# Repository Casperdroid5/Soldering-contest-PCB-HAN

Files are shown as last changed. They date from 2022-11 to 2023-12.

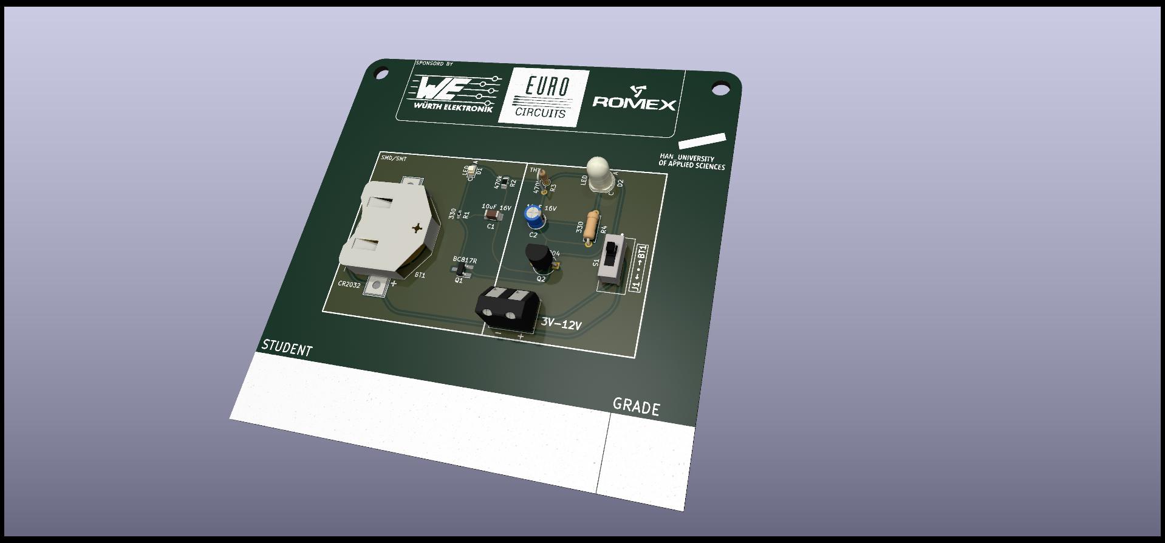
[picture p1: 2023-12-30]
Pictures PCB/Soldering contest PCB HAN.jpg

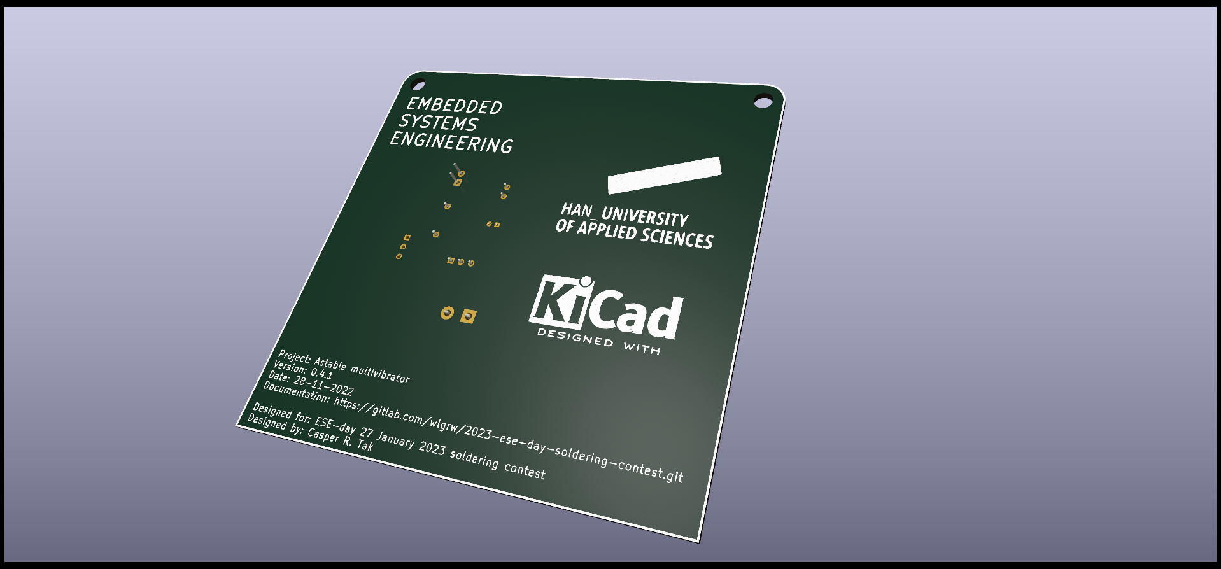
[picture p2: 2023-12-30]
Pictures PCB/Soldering contest PCB HAN-Back.png

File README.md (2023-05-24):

# Soldering Contest PCB (HAN)

The PCB has been created specifically for the soldering contest. It is designed to help students in the ESE course develop their soldering skills for both surface-mount (SMD) and through-hole (THT) components of different sizes.

## Key Features

- **Component Variety:** The PCB includes a diverse range of SMD and THT components of different sizes and types. This allows students to practice soldering techniques for various components.

- **Component Footprints:** Different component footprints are included on the PCB to accommodate various package types such as resistors, capacitors, diodes, ICs, and connectors. This exposes students to different soldering techniques required for each component type.

- **Test Points:** The PCB features strategically placed test points that enable instructors to measure the quality of solder joints. These test points assess students' soldering technique and the electrical connectivity of the components.

- **Thermal Pads:** Components with thermal pads are incorporated to test students' ability to handle heat dissipation during soldering. This provides experience in soldering components that require special attention to avoid overheating or cold solder joints.

- **Solder Mask Openings:** Small solder mask openings are introduced on some pads to assess students' precision and control during soldering. This challenges them to avoid bridging adjacent pads or leaving solder residues on the mask.

- **Multiple Soldering Techniques:** The PCB is designed to encourage the use of different soldering techniques. It includes components that require drag soldering, reflow soldering, or hand-soldering under a microscope. This helps students become proficient in a variety of soldering methods.

- **Soldering Station Settings:** Clear guidelines or recommendations for soldering station settings are provided, including temperature, soldering iron tip selection, and solder types suitable for the components on the PCB. This helps students understand the importance of proper soldering equipment setup for different scenarios.

- **Grading Criteria:** A grading rubric is defined, covering soldering technique, joint appearance, component alignment, cleanliness, and electrical continuity. This ensures students understand how their work will be evaluated.

- **Documentation and Resources:** Documentation or resources such as a soldering guide or reference materials are provided for students to refer to during the contest. This helps familiarize them with best practices and techniques before starting their soldering tasks.

- **Safety Considerations:** Emphasis is placed on safety precautions during soldering, including proper ventilation, eye protection, and safe handling of soldering equipment. The contest follows appropriate safety protocols to protect the students and instructors.

## Soldering Tips and Advice

Soldering is a delicate process that requires skill, precision, and attention to detail. Here are some helpful tips and advice to assist students participating in the soldering contest:

1. **Prepare your workspace:** Ensure you have a clean and well-organized workspace. Remove any unnecessary clutter, and have all your tools and components easily accessible. A clutter-free area allows you to focus on the soldering task at hand and reduces the chances of accidental damage or mistakes.

2. **Inspect the PCB and components:** Before starting, carefully inspect the PCB and components for any defects or damage. Check for bent pins, damaged traces, or missing components. Address any issues before proceeding with soldering to avoid complications later.

3. **Choose the right soldering iron tip:** Select an appropriate soldering iron tip based on the component size and type. A fine-point tip works well for small SMD components, while a chisel or screwdriver tip is suitable for larger THT components. Ensure the tip is clean and properly tinned for optimal heat transfer.

4. **Maintain proper temperature:** Set the soldering iron temperature according to the solder and component requirements. Too high a temperature can damage components or lead to overheating, while too low a temperature can result in cold solder joints. Follow the recommended temperature range provided for the contest.

5. **Cleanliness is crucial:** Keep your soldering iron tip clean by regularly wiping it on a damp sponge or brass tip cleaner. This helps remove oxidation and ensures good heat transfer. Additionally, keep the components, PCB, and soldering area clean from flux residues or excess solder. Use flux remover or isopropyl alcohol for cleaning, if necessary.

6. **Practice good soldering technique:** Master the art of soldering by practicing proper technique. Hold the soldering iron like a pen, with a light grip, and apply gentle pressure. Ensure the tip touches both the pad and the component lead simultaneously to allow efficient heat transfer. Feed a small amount of solder at the junction, and let it flow smoothly.

7. **Avoid excessive heat:** Minimize the time the soldering iron spends in contact with the component leads or pads to prevent overheating. Prolonged exposure to heat can damage sensitive components or surrounding parts. Develop a steady and controlled soldering rhythm to ensure quick, yet accurate, soldering.

8. **Prevent solder bridges:** Take care to avoid solder bridges, which occur when solder connects adjacent pads or pins. Use a magnifying glass or a microscope to closely inspect your work, especially when soldering small, closely spaced components. If solder bridges occur, use desoldering braid or a solder sucker to remove excess solder.

9. **Ensure proper joint formation:** Aim for shiny, concave solder joints that indicate a proper bond. Dull or irregular joints may indicate cold solder joints or insufficient solder. If needed, reheat the joint and add a small amount of solder to achieve a well-formed, reliable connection.

10. **Test continuity and functionality:** Once soldering is complete, use a multimeter or other appropriate testing methods to check the electrical continuity and functionality of the soldered components. This ensures that the connections are secure and the circuit operates as intended.

Remember, soldering is a skill that improves with practice. Take your time, be patient, and learn from each soldering experience. Don't hesitate to ask for guidance or clarification if you have any doubts. Enjoy the soldering process and have confidence in your abilities!

*Note: The soldering tips and advice provided here are general guidelines. Always refer to the specific instructions, safety precautions, and grading criteria provided by the contest organizers for accurate information and requirements.*

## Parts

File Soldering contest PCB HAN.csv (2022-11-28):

Source: | C:\Users\crtak\Documents\Projecten\Soldering contest PCB HAN\Solder-contest-PCB-HAN\Soldering contest PCB HAN.kicad_sch
Date: | 28/11/2022 10:49:19
Tool: | Eeschema (6.0.6)
Generator: | C:\Program Files\KiCad\6.0\bin\scripting\plugins/bom_csv_grouped_by_value.py
Component Count: | 15
Individual Components:
Item | Qty | Reference(s) | Value | LibPart | Footprint | Datasheet | Field4
 |  | BT1 | Battery_Cell | Device:Battery_Cell | Battery:BatteryHolder_Keystone_3002_1x2032 | ~
 |  | C1 | 10uF 16V | Device:C_Polarized | Capacitor_SMD:C_1206_3216Metric_Pad1.33x1.80mm_HandSolder | ~
 |  | C2 | 10uF 16V | Device:C_Polarized | Capacitor_THT:CP_Radial_D4.0mm_P2.00mm | ~
 |  | D1 | LED | Device:LED | LED_SMD:LED_0805_2012Metric_Pad1.15x1.40mm_HandSolder | ~
 |  | D2 | LED | Device:LED | LED_THT:LED_D5.0mm_Clear | ~
 |  | H1 | MountingHole | Mechanical:MountingHole | MountingHole:MountingHole_4.3mm_M4 | ~
 |  | H2 | MountingHole | Mechanical:MountingHole | MountingHole:MountingHole_4.3mm_M4 | ~
 |  | J1 | Screw_Terminal_01x02 | Connector:Screw_Terminal_01x02 | TerminalBlock:TerminalBlock_bornier-2_P5.08mm | ~
 |  | Q1 | BC817 | Transistor_BJT:2N3904 | Package_TO_SOT_SMD:SOT-23_Handsoldering | https://assets.nexperia.com/documents/data-sheet/BC817_SER.pdf
 |  | Q2 | 2N3904 | Transistor_BJT:2N3904 | Package_TO_SOT_THT:TO-92_Inline_Wide | https://www.onsemi.com/pub/Collateral/2N3903-D.PDF
 |  | R1 | 330 | Device:R | Resistor_SMD:R_0402_1005Metric | ~
 |  | R2 | 470k | Device:R | Resistor_SMD:R_0805_2012Metric_Pad1.20x1.40mm_HandSolder | ~
 |  | R3 | 470k | Device:R | Resistor_THT:R_Axial_DIN0204_L3.6mm_D1.6mm_P2.54mm_Vertical | ~
 |  | R4 | 330 | Device:R | Resistor_THT:R_Axial_DIN0207_L6.3mm_D2.5mm_P7.62mm_Horizontal | ~
 |  | S1 | SWITCH-SPDT-PTH-11.6X4.0MM-KIT | SparkFun-Switches:SWITCH-SPDT-PTH-11.6X4.0MM-KIT | SnapEDA Library:SW_1825159-1 |  | SWCH-08261
Collated Components:
Item | Qty | Reference(s) | Value | LibPart | Footprint | Datasheet | Field4
1 | 1 | BT1 | Battery_Cell | Device:Battery_Cell | Battery:BatteryHolder_Keystone_3002_1x2032 | ~
2 | 1 | C1 | 10uF 16V | Device:C_Polarized | Capacitor_SMD:C_1206_3216Metric_Pad1.33x1.80mm_HandSolder | ~
3 | 1 | C2 | 10uF 16V | Device:C_Polarized | Capacitor_THT:CP_Radial_D4.0mm_P2.00mm | ~
4 | 1 | D1 | LED | Device:LED | LED_SMD:LED_0805_2012Metric_Pad1.15x1.40mm_HandSolder | ~
5 | 1 | D2 | LED | Device:LED | LED_THT:LED_D5.0mm_Clear | ~
6 | 2 | H1, H2 | MountingHole | Mechanical:MountingHole | MountingHole:MountingHole_4.3mm_M4 | ~
7 | 1 | J1 | Screw_Terminal_01x02 | Connector:Screw_Terminal_01x02 | TerminalBlock:TerminalBlock_bornier-2_P5.08mm | ~
8 | 1 | Q1 | BC817 | Transistor_BJT:2N3904 | Package_TO_SOT_SMD:SOT-23_Handsoldering | https://assets.nexperia.com/documents/data-sheet/BC817_SER.pdf
9 | 1 | Q2 | 2N3904 | Transistor_BJT:2N3904 | Package_TO_SOT_THT:TO-92_Inline_Wide | https://www.onsemi.com/pub/Collateral/2N3903-D.PDF
10 | 1 | R1 | 330 | Device:R | Resistor_SMD:R_0402_1005Metric | ~
11 | 1 | R2 | 470k | Device:R | Resistor_SMD:R_0805_2012Metric_Pad1.20x1.40mm_HandSolder | ~
12 | 1 | R3 | 470k | Device:R | Resistor_THT:R_Axial_DIN0204_L3.6mm_D1.6mm_P2.54mm_Vertical | ~
13 | 1 | R4 | 330 | Device:R | Resistor_THT:R_Axial_DIN0207_L6.3mm_D2.5mm_P7.62mm_Horizontal | ~
14 | 1 | S1 | SWITCH-SPDT-PTH-11.6X4.0MM-KIT | SparkFun-Switches:SWITCH-SPDT-PTH-11.6X4.0MM-KIT | SnapEDA Library:SW_1825159-1 |  | SWCH-08261

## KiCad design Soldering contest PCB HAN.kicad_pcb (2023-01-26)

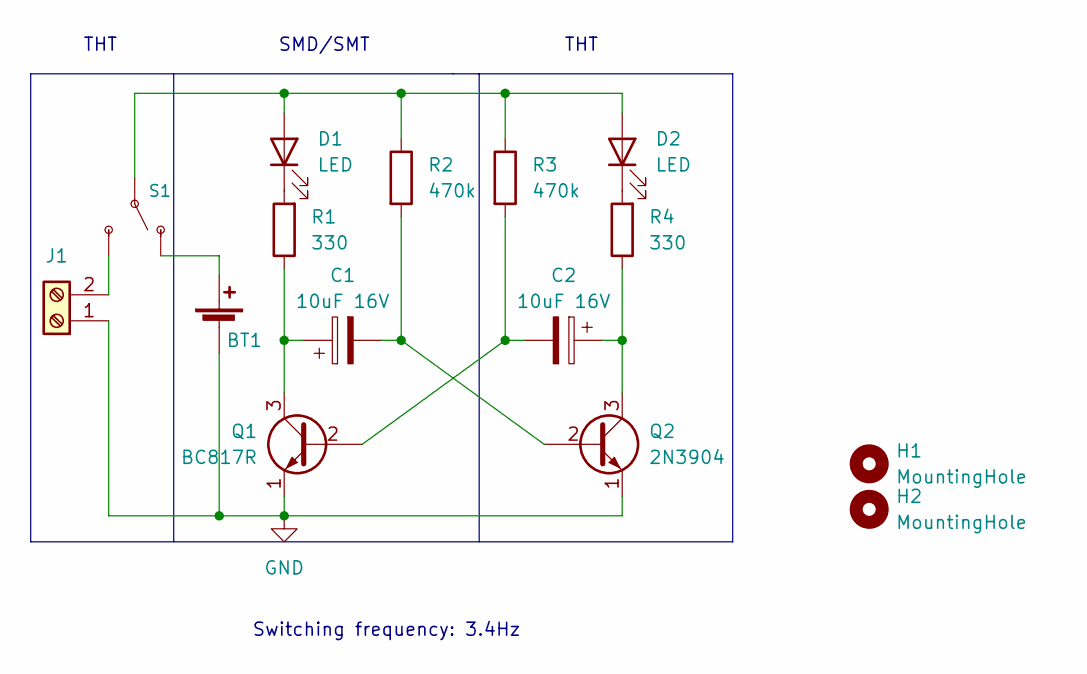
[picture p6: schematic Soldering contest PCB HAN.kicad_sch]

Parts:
BT1: Battery_Cell; BatteryHolder_Keystone_3002_1x2032
C1: 10uF 16V; C_1206_3216Metric_Pad1.33x1.80mm_HandSolder
C2: 10uF 16V; CP_Radial_D4.0mm_P2.00mm
D1: LED; LED_0805_2012Metric_Pad1.15x1.40mm_HandSolder
D2: LED; LED_D5.0mm_Clear
H1, H2: MountingHole; MountingHole_4.3mm_M4
J1: Screw_Terminal_01x02; TerminalBlock_bornier-2_P5.08mm
Q1: BC817R; SOT-23_Handsoldering
Q2: 2N3904; TO-92_Inline_Wide
R1: 330; R_0402_1005Metric
R2: 470k; R_0805_2012Metric_Pad1.20x1.40mm_HandSolder
R3: 470k; R_Axial_DIN0204_L3.6mm_D1.6mm_P2.54mm_Vertical
R4: 330; R_Axial_DIN0207_L6.3mm_D2.5mm_P7.62mm_Horizontal
S1: SWITCH-SPDT-PTH-11.6X4.0MM-KIT; SW_1825159-1

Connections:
GND: BT1.2 (-), J1.1, Q1.1 (E), Q2.1 (E)
unnamed: BT1.1 (+), S1.1 (O)
unnamed: C1.1, Q1.3 (C), R1.1
unnamed: C1.2, Q2.2 (B), R2.2
unnamed: C2.1, Q2.3 (C), R4.1
unnamed: C2.2, Q1.2 (B), R3.2
unnamed: D1.1 (K), R1.2
unnamed: D1.2 (A), D2.2 (A), R2.1, R3.1, S1.2
unnamed: D2.1 (K), R4.2
unnamed: J1.2, S1.3 (S)

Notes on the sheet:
SMD/SMT
THT
Switching frequency: 3.4Hz

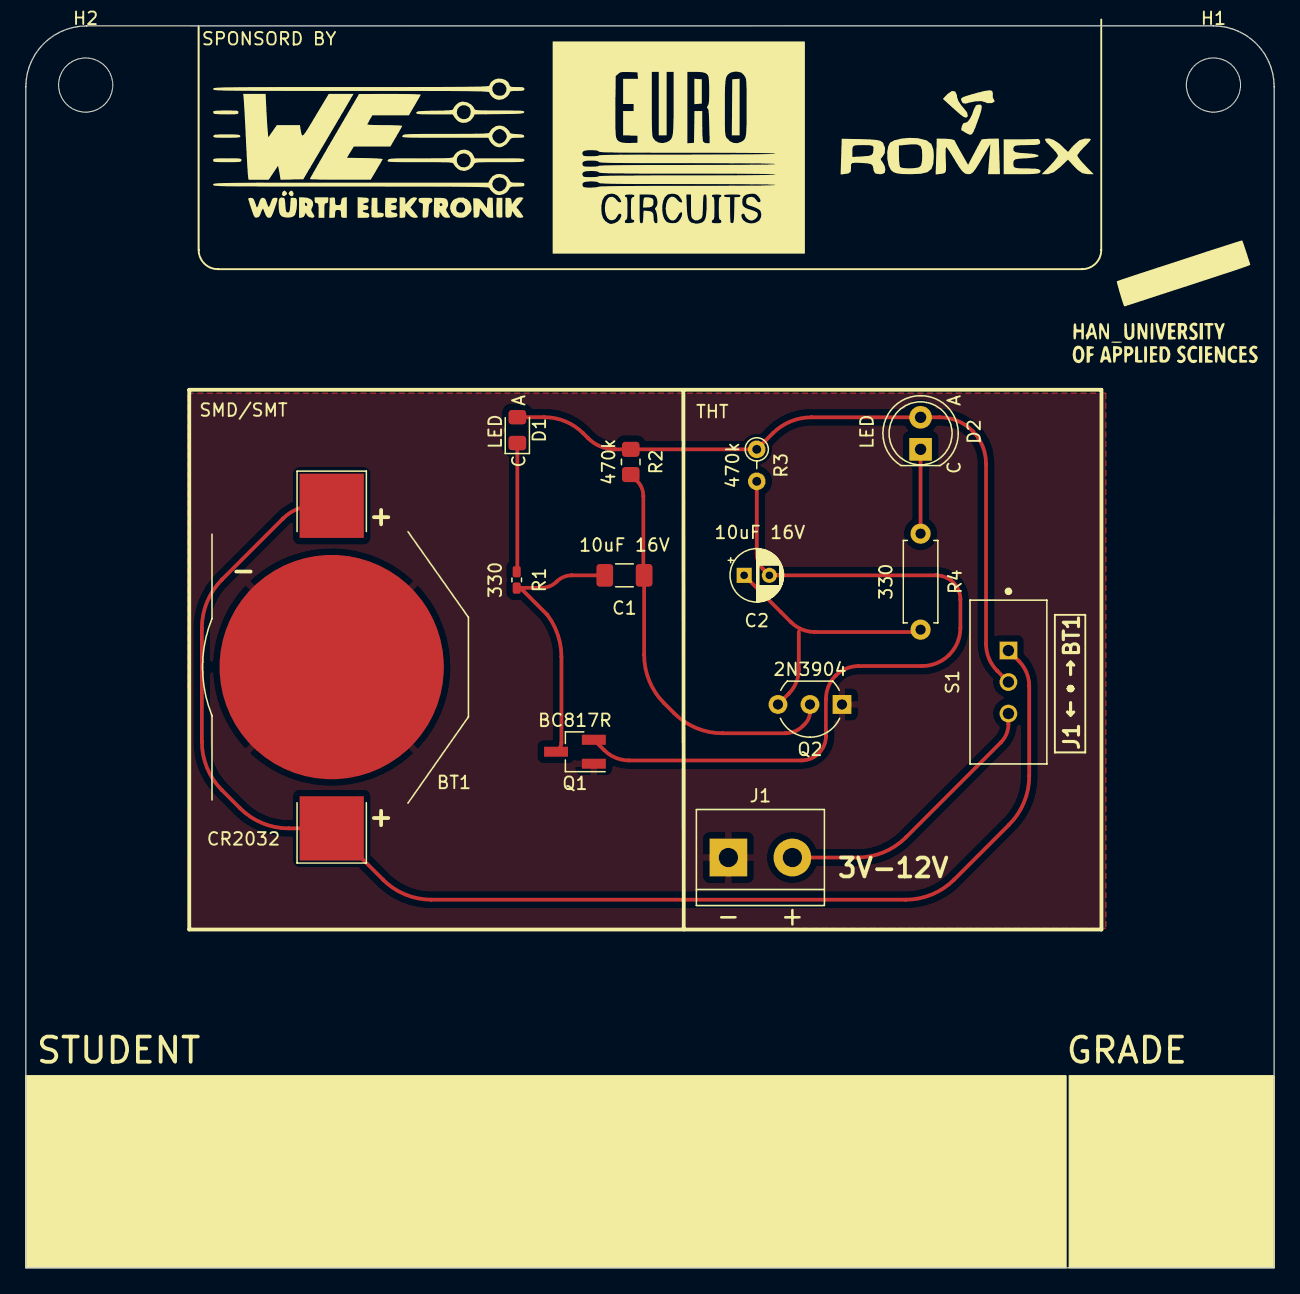
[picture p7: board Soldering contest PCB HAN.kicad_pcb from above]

Board: 2 copper layers, 99.1 x 98.6 mm, 15 parts (0 on the bottom side), 10 nets.

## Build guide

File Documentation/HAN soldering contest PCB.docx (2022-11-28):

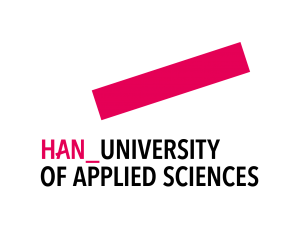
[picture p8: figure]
HAN University of Applied Sciences - Wikipedia

HAN soldering contest PCB

Student: Casper R. Tak

Studentnumber: 657313

Client: Remko Welling

High School: HAN Arnhem

Education: Embedded Systems Engineering

Version: V0.1

Date: 18-11-2022

# Goal

Main Goal: Creating an small and easy PCB that learns the student how to solder a variant of SMD and THT components.

# PCB requirements

Requirement number | Description
T1.0 | Contains THT components
T1.1 | Contains different sizes of THT components
T1.1 | Contains “standing up” and “laying down” components
T1.2 | Contains at least one header
T2.0 | Contains SMD/SMT components
T2.1 | Contains different sizes of SMD components: 1206, 0805, 0402 and SOT23
T3.0 | The PCB should be a squire, smaller than 10 by 10 cm
T3.1 | The PCB must contain mounting holes of 5 mm
T3.2 | The PCB design should be single layer
T3.3 | The PCB silkscreen should contain the logo of the HAN, Wurth Electronics, Eurocircuits
T3.31 | The Logo’s should have roughly the same size
T3.32 | The PCB silkscreen should contain 2 white bars where the students name and grade can be written on
T3.33 | The PCB silkscreen could contains soldering tips on flux, temperature settings for relflow ovens and hand soldering
T3.34 | The silkscreen should clearly state the polarity of all components that have polarity
T3.4 | All components must be orderd by Wurth Electronics (requirement by sponsor)

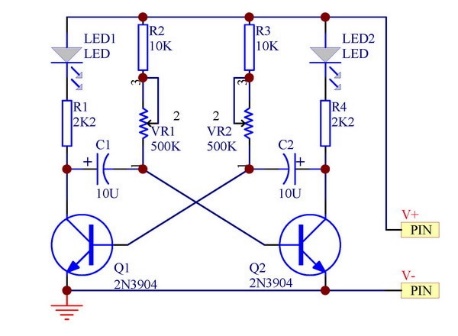
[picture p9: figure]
Verstelbare Transistor Astabiele Multivibrator Circuit Leren Kit, Led Knippert.|kit kits|circuit kitkit circuit - AliExpress

T3.5 | The circuit used will be: Astable multivibrator
T3.51 | (VR1 and VR2 will be replaced by fixed resistors)
T3.52 | Q1 and Q2 should also have alternative options listed for both SMD and THT components
T3.53 | LED1 and LED2 may have different colors
T4.0 | Soldering the PCB should roughly take 10 minutes

# Soldering (safety) tips/hints:

TIPS:

-Wear safety goggles

-Avoid breathing in the solder fumes

-Use the appropriate soldering tip for the job

-350°C-400°C are usual soldering temperatures

-"Pre tin" components/wires

-Heat the pad and the component while adding tin

-Use a helping hand or board clamp

-Pliers make handling small components easier

-Solder paste requires around 220°C to melt

-Low melt solder/hot air is the easiest way to remove

components with many pins

-Avoid dull looking solder joints

# Sponsors/logos

Wurth electronics

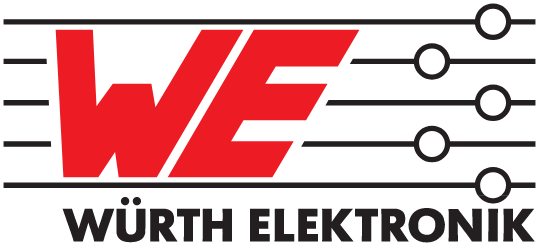
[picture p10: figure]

Eurocircuits

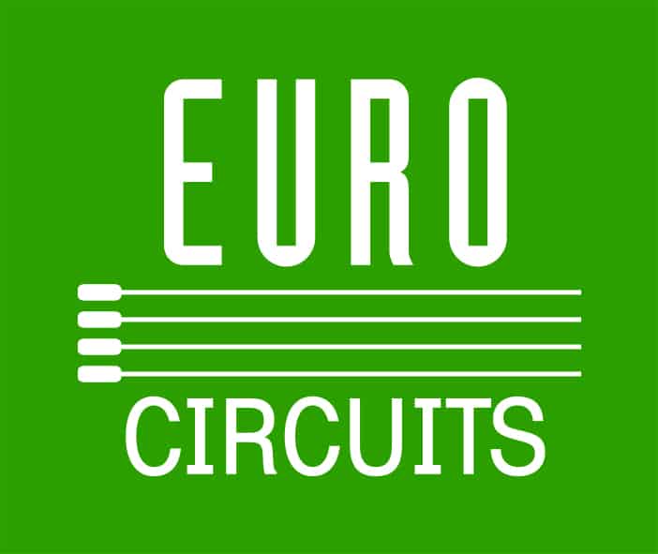
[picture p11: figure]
Student - Eurocircuits

Romex

HAN university of applied sciences

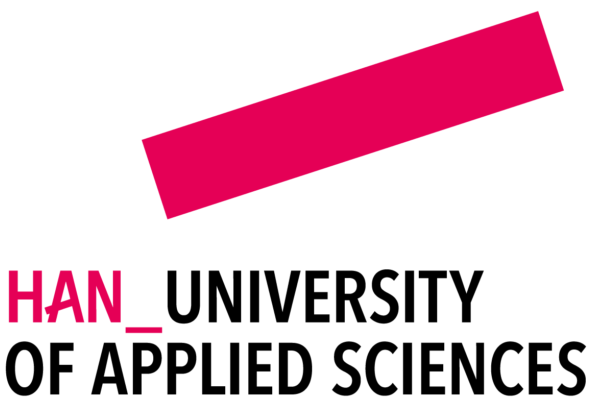
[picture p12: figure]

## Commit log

2022-11-18 Initial commit
    added schematic with details on project
    added requirements file (empty)
    [Soldering contest PCB HAN.kicad_pcb, Soldering contest PCB HAN.kicad_sch]
2022-11-18 Schematic created
    Basic circuit has been drawn
    [Soldering contest PCB HAN.kicad_sch]
2022-11-18 added values and references to components
    Some values may be tweaked later
    [Soldering contest PCB HAN.kicad_sch]
2022-11-18 defined smd and tht sides of schematic
    [Soldering contest PCB HAN.kicad_sch]
2022-11-18 assigned footprints
    [Soldering contest PCB HAN.kicad_sch]
2022-11-18 Update README.md
    changed name to soldering
2022-11-18 improved schematic board size
    [Soldering contest PCB HAN.kicad_pcb, Soldering contest PCB HAN.kicad_sch]
2022-11-18 replaced q1 footprint
    replaced with sot23 handsolderable
    [Soldering contest PCB HAN.kicad_pcb, Soldering contest PCB HAN.kicad_sch]
2022-11-18 archived 3d model, created general layout
    [Soldering contest PCB HAN.kicad_pcb]
2022-11-18 changed Q2 footprint
    to to92 wide
    [Soldering contest PCB HAN.kicad_pcb]
2022-11-18 changed r3 footprint
    smaller, so it's clear that it has to be soldered vertically
    [Soldering contest PCB HAN.kicad_pcb, Soldering contest PCB HAN.kicad_sch]
2022-11-18 Wiring complete
    [Soldering contest PCB HAN.kicad_pcb]
2022-11-18 added ground plane
    for demonstration purposes
    [Soldering contest PCB HAN.kicad_pcb]
2022-11-18 added tips and sponsors to documentation
    [Soldering contest PCB HAN.kicad_pcb]
2022-11-18 started on silkscreen
    added student and grade boxes
    [Soldering contest PCB HAN.kicad_pcb]
2022-11-18 rounded corners
    [Soldering contest PCB HAN.kicad_pcb]
2022-11-18 added tips and project name to backsilk
    [Soldering contest PCB HAN.kicad_pcb]
2022-11-18 improved silkscreen text and made it pretier
    [Soldering contest PCB HAN.kicad_pcb]
2022-11-18 finished pcb design V0.1
    [Soldering contest PCB HAN.kicad_pcb]
2022-11-18 changed terminal position
    [Soldering contest PCB HAN.kicad_pcb]
2022-11-18 incorporated Remko's feedback
    -added Romex logo
    -added text: "Designed for: ESE-day 27 January 2023 soldering contest"
    -moved terminal to mid bottom to balance weight
    -
    [Soldering contest PCB HAN.kicad_pcb]
2022-11-18 removed tips, added ESE txt
    [Soldering contest PCB HAN.kicad_pcb]
2022-11-18 added todo list
    [Soldering contest PCB HAN.kicad_pcb]
2022-11-21 add bat, switch changed schematic
    [Soldering contest PCB HAN.kicad_pcb, Soldering contest PCB HAN.kicad_sch]
2022-11-21 improved wiring and connected everything
    [Soldering contest PCB HAN.kicad_pcb, Soldering contest PCB HAN.kicad_sch]
2022-11-21 Working on ERC
    [Soldering contest PCB HAN.kicad_pcb]
2022-11-21 archived 3d models
    [Soldering contest PCB HAN.kicad_pcb, Soldering contest PCB HAN.kicad_sch]
2022-11-21 added component values to silkscreen
    [Soldering contest PCB HAN.kicad_pcb]
2022-11-21 Finished V0.2
    -added Remko's feedback
    -changed a few component names to their smd parts
    -added gitlab repo link to pcb (not yet uploaded to gitlab)
    [Soldering contest PCB HAN.kicad_pcb, Soldering contest PCB HAN.kicad_sch]
2022-11-21 added bom and schematic pdf
2022-11-21 improved values
    [Soldering contest PCB HAN.kicad_pcb, Soldering contest PCB HAN.kicad_sch]
2022-11-21 updated bom
2022-11-21 Added the correct values to the components
    -R val
    -C val
    [Soldering contest PCB HAN.kicad_pcb, Soldering contest PCB HAN.kicad_sch]
2022-11-21 Finished V0.2
    -added interactive BOM
    -added improved schematic
    [Soldering contest PCB HAN.kicad_pcb, Soldering contest PCB HAN.kicad_sch]
2022-11-21 added rounded tracks version of V0.2
    [Soldering contest PCB HAN.kicad_pcb]
2022-11-22 small improvements on silkscreen
    [Soldering contest PCB HAN.kicad_pcb]
2022-11-28 enh board
    -added mounting holes
    -updated silkscreen date
    -changed R1 footprint to match ERC
    [Soldering contest PCB HAN.kicad_pcb, Soldering contest PCB HAN.kicad_sch]
2022-11-28 alligned center of pcb
    [Soldering contest PCB HAN.kicad_pcb]
2022-11-28 added new interactive bom
2022-11-28 added BOM
    [Soldering contest PCB HAN.csv]
2022-11-28 final silkscreen improvements
    [Soldering contest PCB HAN.kicad_pcb]
2022-11-28 finalised V0.4
    -cleanup and recenterd
    [Soldering contest PCB HAN.kicad_pcb]
2022-11-28 updated pcb v0.4 file
    [Soldering contest PCB HAN.kicad_pcb]
2022-12-01 added kicad logo
    [Soldering contest PCB HAN.kicad_pcb]
2022-12-01 added kicad logo and updated version number
    [Soldering contest PCB HAN.kicad_pcb]
2023-01-26 Updated component
    BC817 -> BC817R
    [Soldering contest PCB HAN.kicad_pcb, Soldering contest PCB HAN.kicad_sch]
2023-05-24 Update README.md
    extension on soldering contest itself, and safety/tips
2023-12-30 added pictures of board
